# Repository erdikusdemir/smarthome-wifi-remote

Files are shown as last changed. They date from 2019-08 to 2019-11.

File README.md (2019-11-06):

I am working on this project on left over times from my PhD thesis.  
For the version based on TCP protocol: https://github.com/erdikusdemir/smarthome-wifi-remote-tcp  

# DESCRIPTION 

Portable remote controller to control smart home devices over MQTT protocol. It is based on ESP8266 with OLED LCD and rotary encoder.
Remote can control switches, dimmers, fans, and temperature controllers.

The remote controller communicates with Node-Red flow by MQTT JSON messages. Node-Red flow converts the signals from both remote and HA side and makes implementation easier. Items you would like to control by remote can be edited by "config file" function. Arduino sketch only configures Wifi and MQTT settings. All the item information are called at the initialization stage of the remote.

Wemos kill its power after 15 secs of idle time. Thus, power consumption of the remote is zero when it is not used. 

Hardware is consist of;
1. Wemos D1 mini Pro,
2. A clickable rotary encoder,
3. 0.96" I2C 128x64 OLED display,
4. Wemos battery shield,
5. LIPO battery,
6. 3D printed enclosure (under progress),  
7. TPS27081ADDCR load switch,  
8. 2222A NPN transistor,  
9. 330, 1 k, and 1 MOhm resistors.  

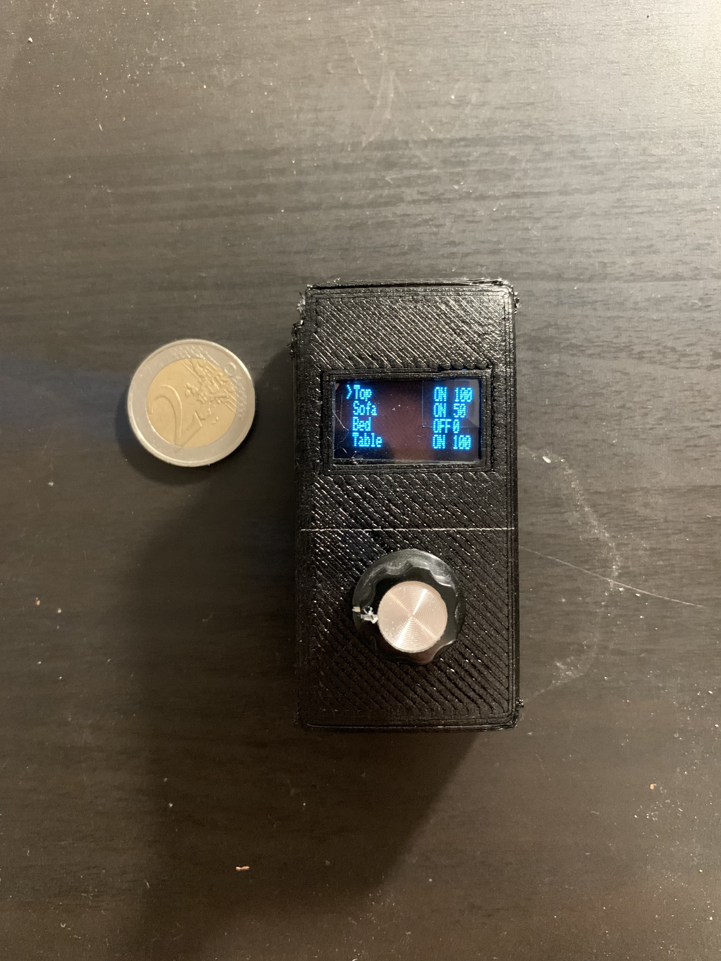
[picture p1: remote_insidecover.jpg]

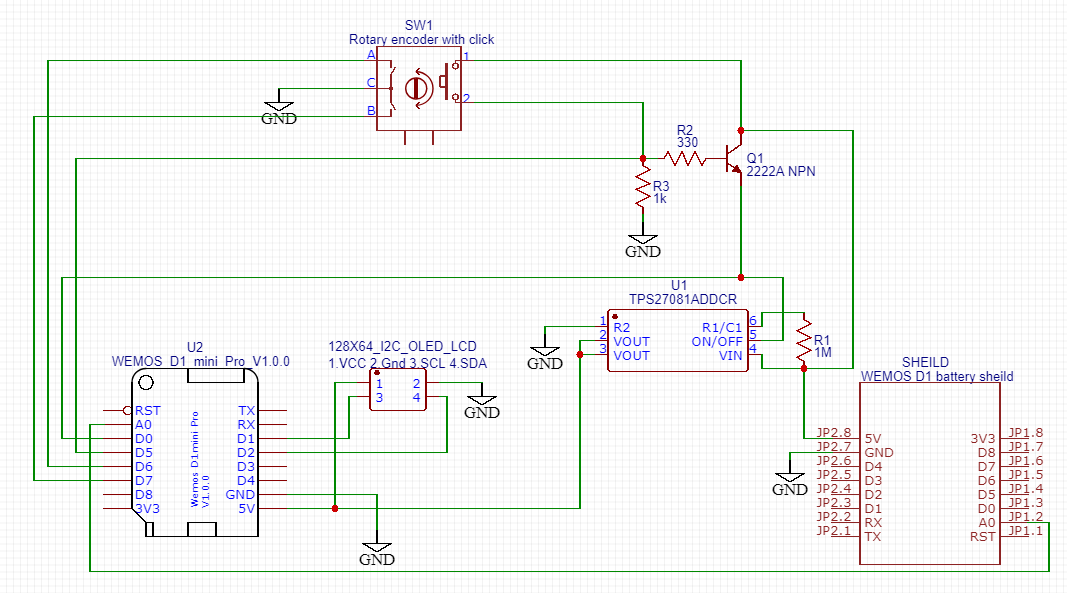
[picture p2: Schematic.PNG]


# Instructions:  
1. Follow the schematic,  
2.1. Open the Arduino sketch and update your wifi and MQTT server information,  
2.2. Copy the libraries to documents/Arduino folder,  
3.1. Copy NodeRed flow into your NodeRed server,  
3.2. Configure your HA and MQTT servers,  
3.3. Configure your items by editing "config file" function,  
(id: order in your OLED screen, HAid: id name of item you want to control, type: switch(0), dimmer(1), or temperature controller(2))  
4.4. Deploy the node and everything should works.  

# To do list:
1. Sometimes, during booting, remote can not collect the Json messages from Node-red and creates a blank page. Apperently, during the allocation of the memory, ESP has a problem to allocate big chunk of memory at once.   
2. (done!) Button of the encoder can not sense fast pushes. Cycle of the main loop is not fast enough.(Interrupt implemented.)  
3. Case is too bulky.

# Limitations:  
The number of an item is fixed to 20 because of code restrictions but it is possible to increase inside the Arduino code.

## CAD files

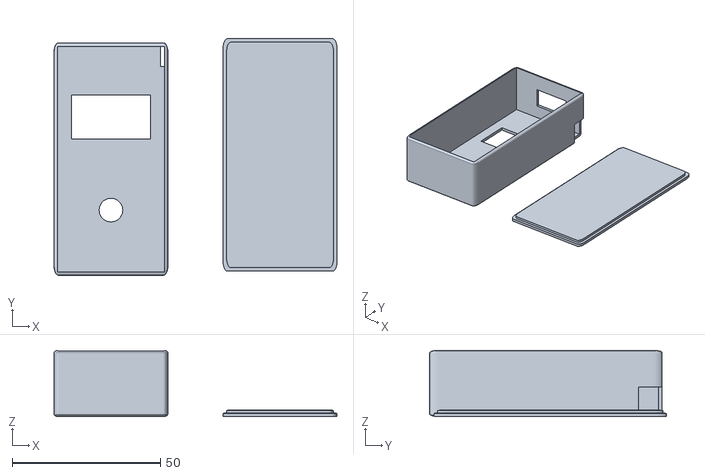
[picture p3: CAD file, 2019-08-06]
cover.stl
95.4 x 79.8 x 22.4

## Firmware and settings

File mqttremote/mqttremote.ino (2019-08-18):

#ifdef ESP8266
extern "C" {
#include "user_interface.h"
}
#endif
#include <SPI.h>
#include <Wire.h>
#include <Adafruit_GFX.h>
#include <Adafruit_SSD1306.h>
#include "Arduino.h"
#include <ESP8266WiFi.h>
#include <PubSubClient.h>
#include "ArduinoJson.h"

// Update these with values suitable for your network.
const char* deviceName = "remote1";// if more than 1 remote is exist, change the devicename.
const char* ssid = "yourssid";
const char* password = "andpassword";
const char* mqtt_server = "yourmqttserverip";
const char* mqtt_clientid = deviceName;
const char* mqtt_username = "username";
const char* mqtt_password = "password";
const char* outTopic = "kumanda1/in";
const char* inTopic = "kumanda1/out";
IPAddress ip(192, 168, 1, 11); //IP Address for remote
IPAddress gateway(192, 168, 1, 1);   //IP Address of your WiFi Router (Gateway)
IPAddress subnet(255, 255, 255, 0);  //Subnet mask
IPAddress dns(192, 168, 1, 1);  //DNS

#define PIN_A D6    //ky-040 clk pin, interrupt, 
#define PIN_B D7    //ky-040 dt  pin,            
int killsw = D0;
int encbtn = D5;

bool btnstate = LOW;
bool laststate = LOW;
bool btnpressed= LOW;
unsigned long now = 0;
unsigned long lastbouncetime =0;
int debouncetime = 150;
int multiclicktime =400;
int longclicktime = 1000;
int clickcount = 0;
int clickcluck = 0;

byte currValueAB;
byte prevValueAB;
int counter=0;


StaticJsonBuffer<2000> JSONBuffer;
//const size_t bufferSize = JSON_OBJECT_SIZE(7) + 70;
//DynamicJsonBuffer JSONBuffer(bufferSize);
#define OLED_RESET -1
#define OLED_VCC D3
Adafruit_SSD1306 display(OLED_RESET);
WiFiClient espClient;
PubSubClient client(espClient);

const int maxitems= 20; //max number of item can be allocated by memory :( only 5 page of item
char data[80];
char data2[80];
int mid=3;
const char* menu0[maxitems] = {"id1", "id2", "id3", "id4"};
boolean state[maxitems] = {0, 0, 0, 0};
String statetemp;
int value0[maxitems] = {0, 0, 0, 0};
int value1[maxitems] = {0, 0, 0, 0};
int type[maxitems] = {0,0,0,0};
boolean mainmenu = 1;
boolean initseq = -1;
int seqcounter = 0;
int dispcursor=0;
int syscursor=0;
long lastupdatetimer=0;
long sleeper=0;
boolean lastreflesh = 0;
int page=0;
int maxscan=3;
boolean outputchanged=0;
boolean ssaver = 0;
long basla=0;
float tempread[maxitems] = {0,0,0,0};
int batlvl[3] = {0,0,0};
int avgbatlvl = 0;
long battimer = 0;

void batlevel(){
batlvl[2]=batlvl[1];
batlvl[1]=batlvl[0];
batlvl[0] = analogRead(A0);
avgbatlvl = (batlvl[0]+batlvl[1]+batlvl[2])/3;
} //end of batlevel

void setup() {
pinMode(killsw,OUTPUT);
digitalWrite(killsw,HIGH);
basla=millis();
Serial.begin(115200);
WiFi.mode(WIFI_STA);
WiFi.hostname(deviceName);
WiFi.config(ip, subnet, gateway, dns);
WiFi.begin(ssid, password);
pinMode(PIN_A,INPUT_PULLUP); //enable internal pull-up resistors 
pinMode(PIN_B,INPUT_PULLUP);
attachInterrupt(digitalPinToInterrupt(PIN_A),encmove,CHANGE);  //call encmove()    when high->low or high->low changes happened
attachInterrupt(digitalPinToInterrupt(PIN_B),encmove,CHANGE);
pinMode(encbtn, INPUT);
attachInterrupt(digitalPinToInterrupt(encbtn),btnintr,FALLING);
display.begin(SSD1306_SWITCHCAPVCC, 0x3C);  // initialize with the I2C addr 0x3C (for the 128x64)
//display.begin(SSD1306, 0x3C);
display.clearDisplay();
display.setTextSize(1);
display.setTextColor(WHITE);
display.setCursor(32,12);
display.println("Loading...");
display.display();
//batlevel();
client.setServer(mqtt_server, 1883);
client.setCallback(callback);
sleeper=millis();
battimer=millis();
}//end of setup


void loop() { //--------------------------------------------------void loop--------------------
if(!client.connected()) {
if (WiFi.status() == WL_CONNECTED){
reconnect();
if(client.connected()) initdata();
}
else{
delay(10);
Serial.print(".");
}
} //client if
client.loop();
btnupdate();
if(initseq==0)screenhandler();
if(outputchanged&&(lastupdatetimer<millis()-200)){outputhandler();lastupdatetimer=millis();}
else {if(outputchanged&&value0[dispcursor]==100)outputhandler();if(outputchanged&&value0[dispcursor]==0)outputhandler();}
if (millis()>1000+battimer){batlevel();battimer=millis();}//bat level
if (millis()>15000+sleeper)digitalWrite(killsw,LOW);//kill switch
}//end of loop

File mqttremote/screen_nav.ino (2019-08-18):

void screenhandler(){
if(dispcursor==-1)page=-1;
else page=dispcursor/4;
if(page==-1){ //maintenance menu
display.setCursor(8,0); //setup item1
display.println("BAT lvl: " + String(avgbatlvl));
display.setCursor(8,8); //setup item2
display.println("SSID: ");
display.setCursor(42,8); //setup item2
display.println(WiFi.SSID());
display.setCursor(8,16); //setup item3
display.println("IP: ");
display.setCursor(26,16); //setup item3
display.println(WiFi.localIP());
display.setCursor(8,24); //setup item4
//display.println("TCP connection: ");
if(client.state()==0)display.println("MQTT is connected.");
else display.println("MQTT is not connected.");
}// end of if page
else {
maxscan=3;
if((mid-(page+1)*4<4)&&(page==mid/4))maxscan=mid%4;
display.setCursor(0,(dispcursor%4)*8);//cursor
display.println(">");
for (int i=0; i <= maxscan; i++){
display.setCursor(8,i*8);
display.println(menu0[i+page*4]);
display.setCursor(90,i*8);
if ((type[i+page*4]==2)&&(state[i+page*4]!=0)){
display.println(value1[i+page*4]);
}
else{
if(state[i+page*4])statetemp="ON";
else statetemp="OFF";
display.println(statetemp);
}
if (type[i+page*4]>=1){
display.setCursor(110,i*8);
display.println(value0[i+page*4]);
}//end type
}//end for
}//end of else page
display.display();
display.clearDisplay();
}//end screenhandler

void encmove()
{
noInterrupts();
currValueAB  = digitalRead(PIN_A) << 1;
currValueAB |= digitalRead(PIN_B);
switch ((prevValueAB | currValueAB))
{
case 0b0001: case 0b1110://CW states for 1 count  per click, use "case 0b0001: case 0b1110: case 0b1000: case 0b0111:" for CW states for 2 counts per click
dispcursorupdate(+1);
break;
case 0b0100: case 0b1011://CCW states for 1 count  per click, use "case 0b0100: case 0b1011: case 0b0010: case 0b1101:" for CCW states for 2 counts per click
dispcursorupdate(-1);
break;
}
prevValueAB = currValueAB << 2;
interrupts();
sleeper=millis();
}//end of encoder move

void dispcursorupdate(int incdec) {
  if(mainmenu){ //artı gidisler
  dispcursor=dispcursor+incdec;
  if(dispcursor<-1)dispcursor=-1;
  if(dispcursor>=mid)dispcursor=mid;
}
else {
  if(type[dispcursor]==2){ //value1 is a set temp
  value1[dispcursor]=value1[dispcursor]+incdec;
  if(value1[dispcursor]<18)value1[dispcursor]=18;
  if(value1[dispcursor]>30)value1[dispcursor]=30;
  }//end if temp 
  if(type[dispcursor]==1){// value0 is set dimmer
  value0[dispcursor]=value0[dispcursor]+10*incdec;
  if(value0[dispcursor]<0)value0[dispcursor]=0;
  if(value0[dispcursor]>100)value0[dispcursor]=100;
  }//end if dimmer
outputchanged=1;
}//end else
}//end of dispcursorupdate

void btnintr()
{
  noInterrupts();
  now =millis();      // get current time
  if (now - lastbouncetime > debouncetime )
  {
  btnpressed = HIGH;
  clickcount++;
  }
  lastbouncetime = now;
  interrupts();
}//end of btnintr

void btnupdate()
{
  now =millis();      // get current time
  if (btnpressed && (now - lastbouncetime) > multiclicktime)
  {
  btnpressed=0;
    if(clickcount != 0) 
    {
      //click sayısı kadar işlem yap
    if(clickcount==1)
    {
    state[dispcursor]=!state[dispcursor];
    if(mainmenu==0){state[dispcursor]=0;mainmenu=1;}
    if(mainmenu&&state[dispcursor]&&(type[dispcursor]==1))value0[dispcursor]=100;
    if(mainmenu&&state[dispcursor]==0&&(type[dispcursor]==1))value0[dispcursor]=0;
    outputchanged=1;
    }
    
    if(clickcount==2)
    {
    if(type){
    if(mainmenu&&state[dispcursor]==0){state[dispcursor]=1;value0[dispcursor]=100;}
    mainmenu=!mainmenu;
    }
    }
    clickcount=0;
    sleeper=millis();
    }
  }

  // Check for "long click"
  if (btnpressed && (now - lastbouncetime > longclicktime))
  {
  if(clickcount != 0) 
  {
  //do sth for long click
  }
  clickcount=0;
  btnpressed=0;
  }
  
}//btnupdate

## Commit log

2018-10-15 noderedflow
    nodered flow which converts messages between HA and remote controller.
2018-10-23 encoder and display code is updated
2019-04-14 new features are added
    battery checker is added.
    paging system is applied.
2019-08-06 v1.5
    temperature sensor is done
    voltage measurement is done
    cover is done
    baterry saver circuit is done
    [cover.stl]
2019-08-18 intterpt button update
